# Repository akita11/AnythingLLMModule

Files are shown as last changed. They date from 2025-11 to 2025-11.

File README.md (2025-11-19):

# AnythingLLM Module

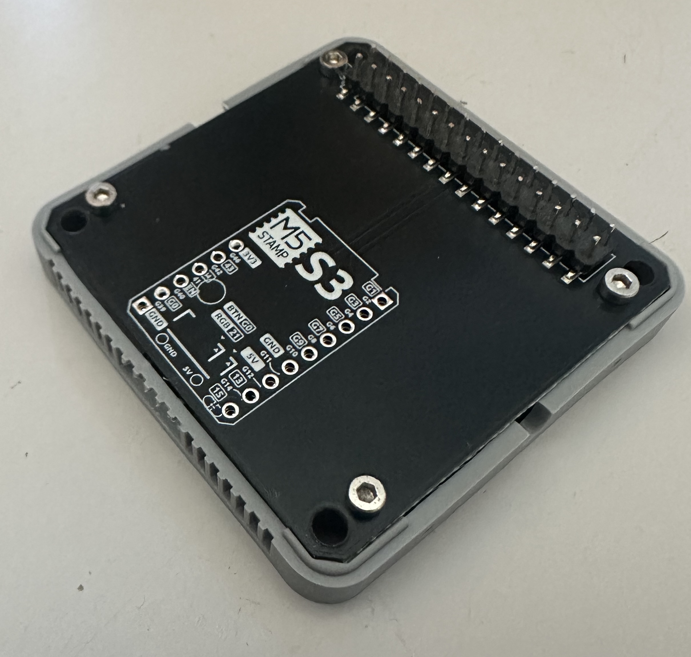
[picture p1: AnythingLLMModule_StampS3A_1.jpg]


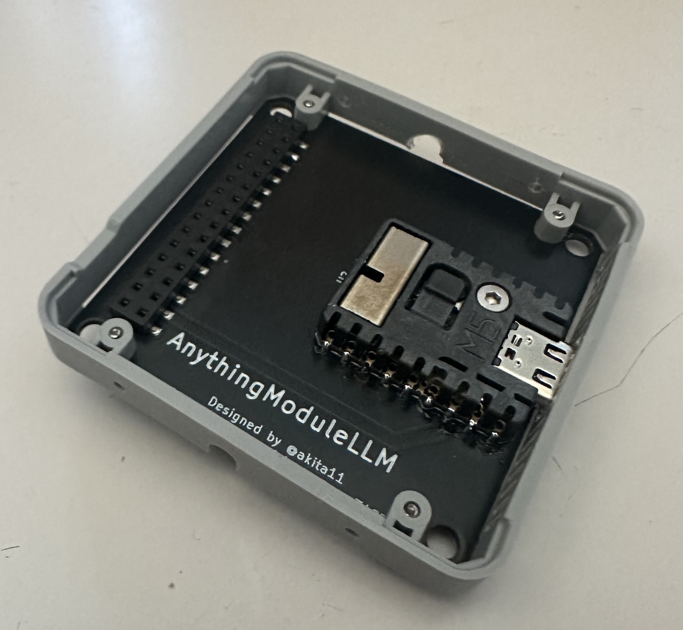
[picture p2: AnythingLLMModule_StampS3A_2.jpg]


M5Stack Coreシリーズに接続し、他のPC等で動作しているAIモデル（大規模言語モデル(LLM)）を、M5Stackから使用できるようにするModuleです。M5Stackとは、M5Stack社のLLM Moduleと同等の接続となるため、ソフトウエア的にはLLM Moduleと同様に扱うことができます。他のPCのLLMへはUSBやWiFiで接続します。M5StampS3Aに必要なソフトウエアを書き込んで使用してください。StampS3Aの取り付け方法が2種類あります。

## StampS3Aを直接とりつけ

[StampS3A](https://www.switch-science.com/products/10377)をリフローはんだ付け等で直接基板に実装します。M5Stack接続用のMbusコネクタもリフローはんだ付け等で基板に実装してください。また必要に応じて、Module Frameをとりつけてください。

## StampS3Aをコネクタを介してとりつけ

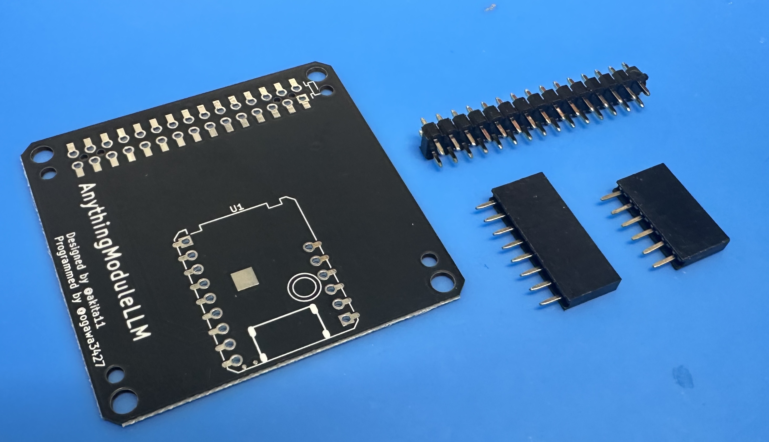
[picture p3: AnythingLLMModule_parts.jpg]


[2.54mmピンヘッダ実装済みのStampS3A](https://www.switch-science.com/products/10734)と、6pと9p（または8p）のピンソケット、およびMbusコネクタまたは2.54mmの2列x15ピンの低プロファイルのピンヘッダを用意します。

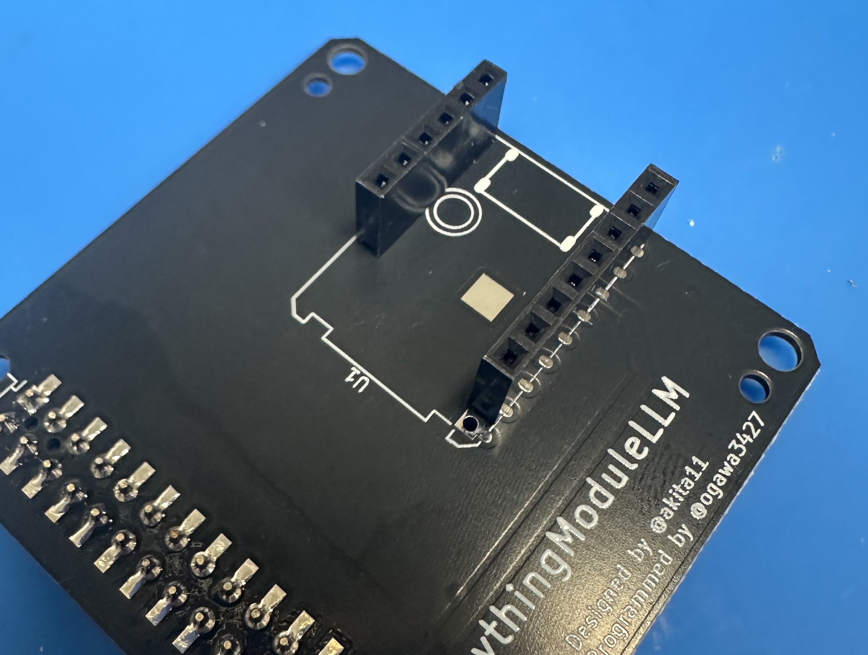
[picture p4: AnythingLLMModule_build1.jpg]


まず基板のこちら面に、6pと9p（または8p）のピンソケットをはんだ付けします。8pソケットを使う場合は、この写真のように1列分を開けた位置にとりつけてください。

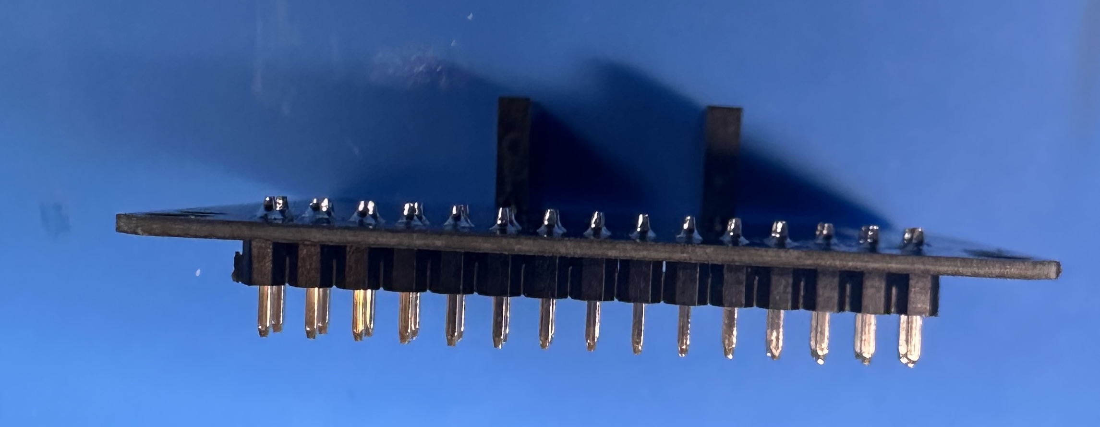
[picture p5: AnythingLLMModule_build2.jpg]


Mbusコネクタをはんだ付け、または2.54mmの2列x15ピンの低プロファイルのピンヘッダをこの写真のようにはんだ付けします。M5Stack本体に接続される側（この写真では下側）の端子の先端が、基板面から5.5mmの位置になるようにしてください。

最後に[2.54mmピンヘッダ実装済みのStampS3A](https://www.switch-science.com/products/10734)を取り付けて完成です。

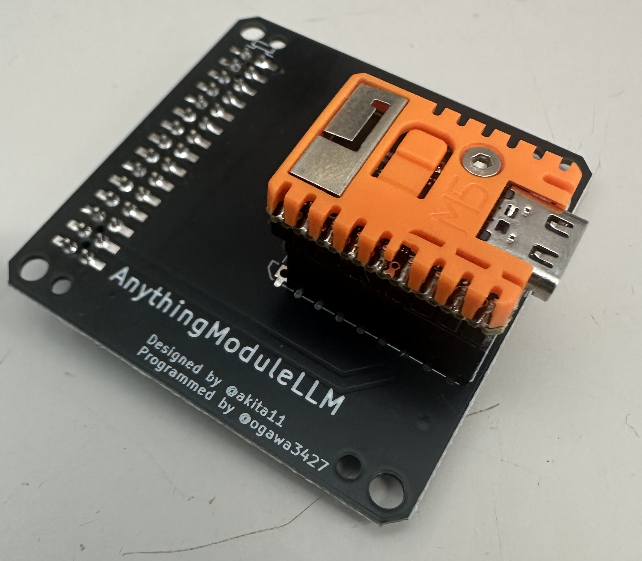
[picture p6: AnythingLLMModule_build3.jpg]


## ソフトウエア

Moduleに書き込む専用のファームウェアがあります。CoreからはLLM-Moduleのライブラリで通信できるように **「一部」** なっています。PC等との通信はWiFiまたはシリアル通信が選択できます。

### Module側

**USB-Cコネクタを接続する時に、ハンダ付けが取れないように注意してください！！！**  
**はがれやすい場合があるので、かならずStampS3を手で押さえて抜き差しすること！！！**  


PlatformIOで[stampS3R](https://github.com/akita11/AnythingLLMModule/tree/main/stampS3R)をビルドして、基板上のM5StampS3に書き込みます。  
このとき、`secrets.h`でPC等のローカルIPアドレス、WiFiのSSID/パスワードを設定してください。  

### PC側

現在はLLMサーバーとしてOllamaのみサポートしています。  
シリアルで接続する場合は[serial](https://github.com/akita11/AnythingLLMModule/tree/main/serial)にあるスクリプトを動かして待機させてください。  
WiFiで接続する場合はOllamaの設定から`Expose Ollama to the network`を有効にしてください。  

### サンプル

サンプルプログラム([coreS3_test](https://github.com/akita11/AnythingLLMModule/tree/main/coreS3_test))を用意しています。お使いのOllamaからアクセス可能なモデル名に変更してお試しください。画面に`ready`と表示されたら、シリアルモニタからテキストを入力してEnterキーを押すと、会話ができます。

### API対応状況(2025/11/20)

- [o] module_llm.checkConnection
- [o] module_llm.llm.setup
- [o] module_llm.llm.inferenceAndWaitResult

## Author

Designed by Junichi Akita (@akita11) / akita@ifdl.jp  
Programmed by Ogawa3427 / ogawa3427@ifdl.jp

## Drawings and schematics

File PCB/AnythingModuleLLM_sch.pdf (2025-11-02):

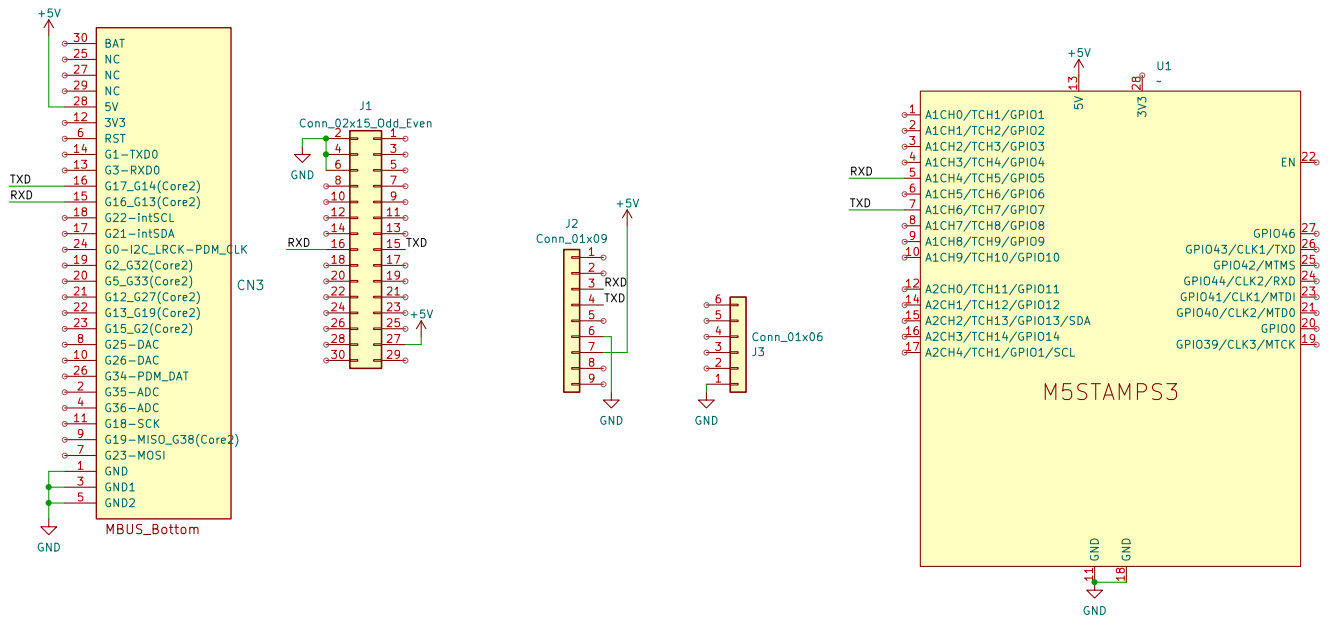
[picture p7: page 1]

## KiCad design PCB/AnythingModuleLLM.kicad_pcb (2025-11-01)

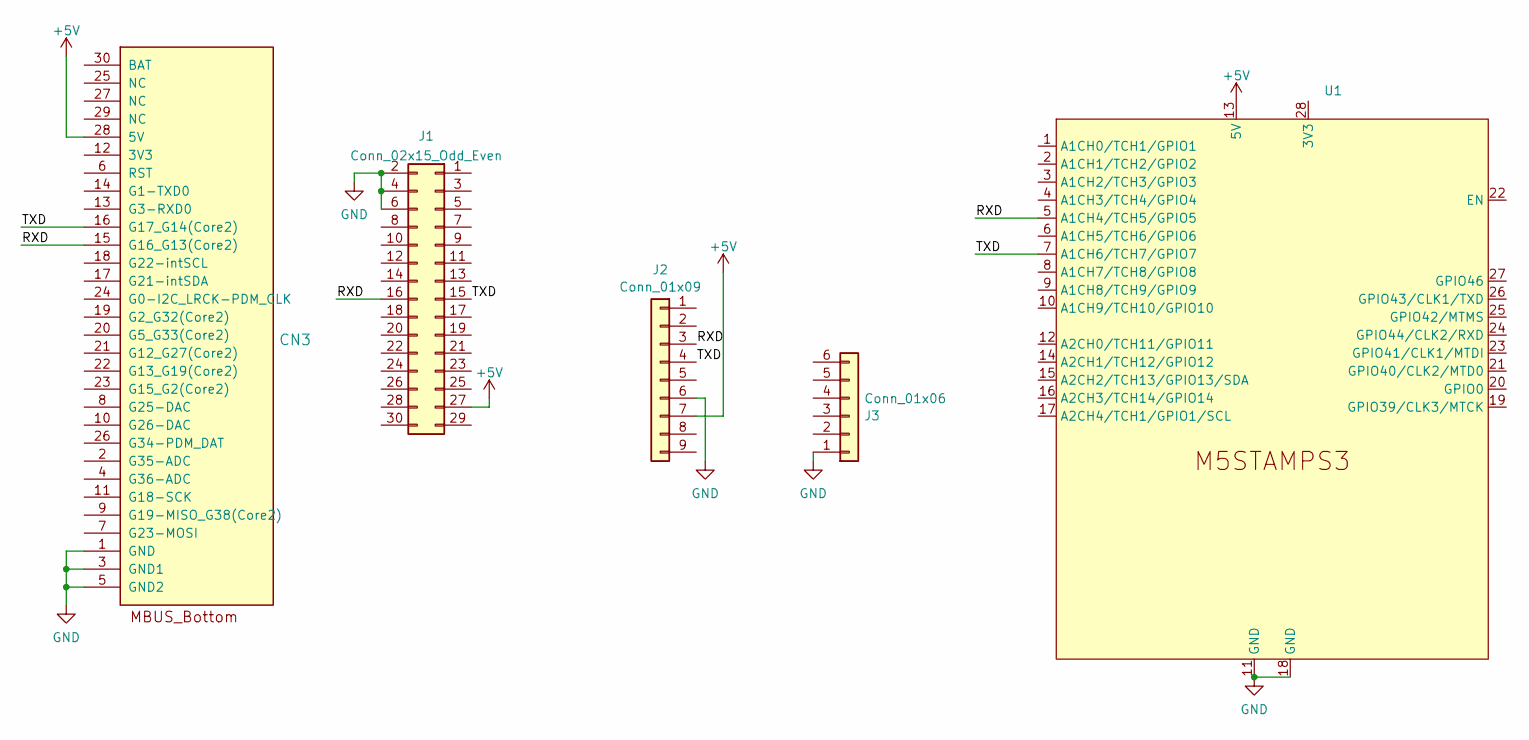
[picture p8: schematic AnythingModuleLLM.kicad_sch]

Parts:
CN3: CON_MBUS_bottom_Core2; M5STACK_BUS_30P
J1: Conn_02x15_Odd_Even; PinHeader_2x15_P2.54mm_Vertical
J2: Conn_01x09; PinHeader_1x09_P2.54mm_Vertical
J3: Conn_01x06; PinHeader_1x06_P2.54mm_Vertical
U1: STAMP-S3-SMD

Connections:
+5V: CN3.28 (5V), J1.27, J2.7, U1.13 (5V)
/RXD: CN3.15 (G16_G13(Core2)), J1.16, J2.3, U1.5 (A1CH4/TCH5/GPIO5)
/TXD: CN3.16 (G17_G14(Core2)), J1.15, J2.4, U1.7 (A1CH6/TCH7/GPIO7)
GND: CN3.1 (GND), CN3.3 (GND1), CN3.5 (GND2), J1.2, J1.4, J1.6, J2.6, J3.1, U1.11 (GND), U1.18 (GND)

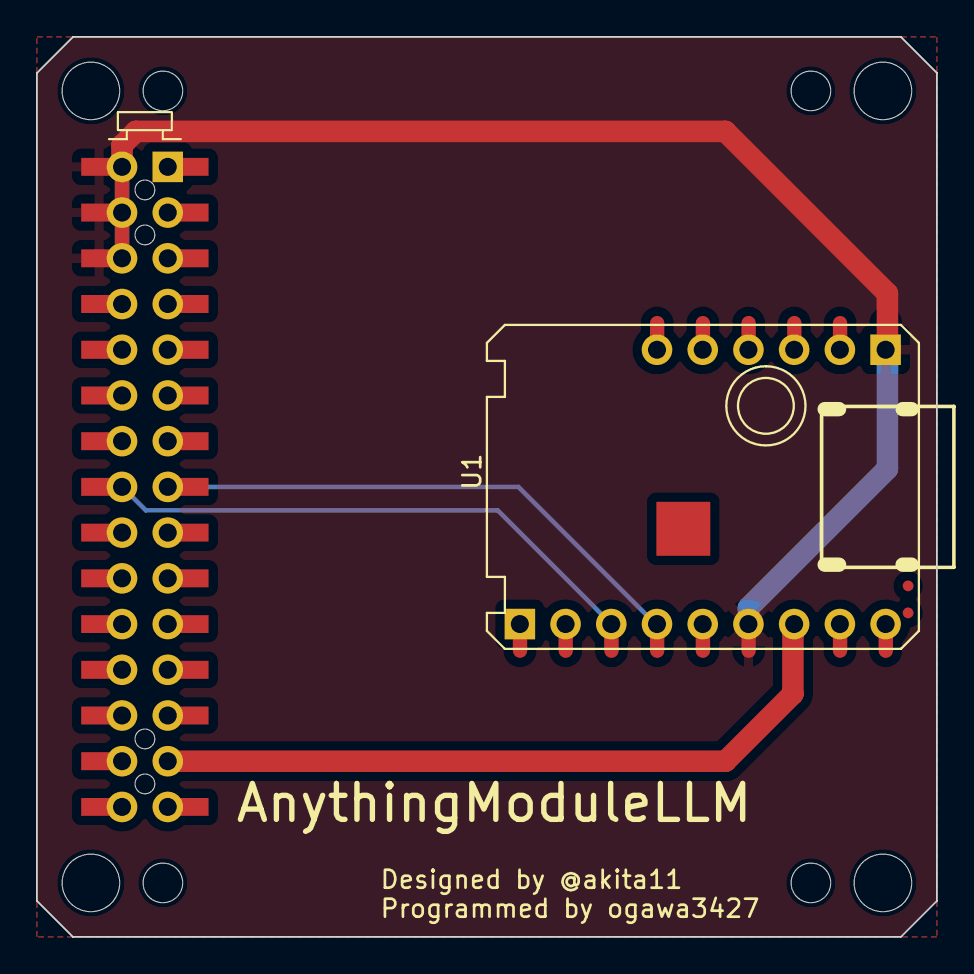
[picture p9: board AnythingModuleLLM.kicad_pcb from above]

Board: 2 copper layers, 50.0 x 50.0 mm, 5 parts (1 on the bottom side), 4 nets.

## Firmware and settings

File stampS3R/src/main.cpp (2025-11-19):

// true: WiFiでLLMサーバーと通信、false: シリアルでLLMサーバーと通信 (デフォルト: true)
#define USE_WIFI_FOR_LLM_COMMUNICATION true

// WiFiを使用するとき true: ステーションモード(既存のWiFiを使用)、false: APモード(これがAPになる) (デフォルト: true)
#define USE_STATION_MODE true

#include <M5Unified.h>
#include <ArduinoJson.h>
#include "common.h"

#if USE_WIFI_FOR_LLM_COMMUNICATION
#include "use_wifi.h"
#else
#include "use_serial.h"
#endif

void setup()
{
  auto cfg = M5.config();
  M5.begin(cfg);

  Serial.begin(9600);
  // Serial2.begin(115200, SERIAL_8N1, RX, TX) の順序
  Serial2.begin(115200, SERIAL_8N1, 7, 5);

  initLED();
  led_sayStart_initialize();
  // initSPIFFS();
  init_communication();
  led_saySuccess_initialize();

  Serial.println("[JSON] JSON reader initialized");
  resetJsonBuffer();
}

void loop()
{
  M5.update();

  // JSONドキュメントを動的に確保（必要に応じてサイズ調整）
  StaticJsonDocument<JSON_BUFFER_SIZE> doc;

  if (readJsonMessage(doc))
  {
    // JSONのパース成功
    Serial.println("[JSON] Parsed successfully:");

    Serial.println("[JSON] Sending handshake: Hello");
    Serial2.println("Hello");

    // JSONを整形して出力
    serializeJsonPretty(doc, Serial);
    Serial.println();

    // 返事用のJSONの元の構造体 をひとつ作る
    ResponseMsg_t response_msg = {};

    if (doc.containsKey("work_id") && doc.containsKey("action"))
    {
      if (doc["work_id"] == "sys")
      {
        response_msg.request_id = doc["request_id"].as<String>();
        response_msg.work_id = "sys";
        if (doc["action"] == "ping")
        {
          Serial.println("[JSON] System ping");
          response_msg.object = "None";
          response_msg.error.code = 0;
          response_msg.error.message = "";
          sendToM5(response_msg);
        }
        else if (doc["action"] == "reset")
        {
          Serial.println("[JSON] System reset");
          response_msg.object = "None";
          response_msg.error.code = 0;
          response_msg.error.message = "";
          response_msg.request_id = "sys_reset";
          response_msg.work_id = "sys";
          sendToM5(response_msg);
          delay(15);
          response_msg.request_id = "0";
          response_msg.work_id = "sys";
          response_msg.object = "None";
          response_msg.error.code = 0;
          response_msg.error.message = "";
          sendToM5(response_msg);
        }
        else if (doc["action"] == "reboot")
        {
          Serial.println("[JSON] System reboot");
        }
        else if (doc["action"] == "version")
        {
          Serial.println("[JSON] System version");
        }
      }
      else if (doc["work_id"] == "llm")
      {
        response_msg.request_id = doc["request_id"].as<String>();
        if (doc["action"] == "setup")
        {
          Serial.println("[JSON] LLM setup");
          // dataフィールドからモデル名を取得
          String model_name = "";
          if (doc["data"].is<JsonObject>())
          {
            JsonObject data_obj = doc["data"];
            if (data_obj["model"].is<String>())
            {
              model_name = data_obj["model"].as<String>();
            }
          }
          else if (doc["data"].is<String>())
          {
            model_name = doc["data"].as<String>();
          }

          if (model_name.length() == 0)
          {
            Serial.println("[JSON] Model name not specified in data field");
            response_msg.error.code = 1;
            response_msg.error.message = "Model name not specified";
            sendToM5(response_msg);
          }
          else
          {
            LLM_Status llm_status = llm_setup(model_name);
            Serial.print("[JSON] LLM setup status: ");
            Serial.println(llm_status);
            if (llm_status != LLM_OLLAMA_OK)
            {
              response_msg.error.code = (llm_status == LLM_OLLAMA_NOT_FOUND) ? 2 : 1;
              response_msg.error.message = (llm_status == LLM_OLLAMA_NOT_FOUND) ? "Model not found" : "LLM setup failed";
              sendToM5(response_msg);
            }
            else
            {
              // work_idを生成（例: "llm_12345"）
              String generated_work_id = "llm_" + String(millis() % 100000);
              response_msg.work_id = generated_work_id;
              current_work_id = generated_work_id;
              response_msg.object = "llm.setup";
              response_msg.error.code = 0;
              response_msg.error.message = "";
              response_msg.request_id = "llm_setup";
              Serial.print("[JSON] LLM setup response: ");
              Serial.print("request_id=");
              Serial.print(response_msg.request_id);
              Serial.print(", work_id=");
              Serial.print(response_msg.work_id);
              Serial.print(", object=");
              Serial.print(response_msg.object);
              Serial.print(", error.code=");
              Serial.print(response_msg.error.code);
              Serial.println();

              sendToM5(response_msg);

              // PCに送る（適当に受信したJSONをそのまま送る）
              String json_str;
              serializeJson(doc, json_str);
              sendToPC(json_str);
            }
          }
        }
        else if (doc["action"] == "inference")
        {
 
        }
      }
      else
      {
        if (doc["action"] == "inference" && doc["request_id"] == "llm_inference")
        {
          Serial.println("[JSON] LLM inference");
          if (doc["object"] == "llm.utf-8.stream")
          {
            Serial.println("[JSON] Using streaming inference");
            OllamaInferenceCommand command;
            command.model = using_model_name;
            command.prompt = doc["data"]["delta"].as<String>();

            LLM_Status llm_status = llm_inference_streaming(command);
            Serial.print("[JSON] LLM inference status: ");
            Serial.println(llm_status);
            if (llm_status != LLM_OLLAMA_OK)
            {
              response_msg.error.code = 1;
              response_msg.error.message = "LLM inference failed";
              sendToM5(response_msg);
            }
          }
          else
          {
            Serial.println("[JSON] Using non-streaming inference");
          }
        }
      }
    }
    // LEDで成功を表示
    blinkLED(COLOR_OK, 1, 50);
  }

  delay(10);
}

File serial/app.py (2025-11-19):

#!/usr/bin/env python3
# bidirectional_serial_http.py
# Python 3.8+
# Requires: aiohttp, pyserial-asyncio
# pip install aiohttp pyserial-asyncio

import asyncio
import argparse
import logging
from aiohttp import web, ClientSession
import serial_asyncio

logging.basicConfig(level=logging.INFO, format="%(asctime)s %(levelname)s: %(message)s")


async def serial_reader_task(reader, post_url, client_session, newline=b"\n"):
    """シリアルから行を読み、HTTP POSTで localhost の URL に送る"""
    while True:
        try:
            line = await reader.readuntil(newline)  # newlineで区切る
        except asyncio.IncompleteReadError as e:
            if e.partial:
                line = e.partial
            else:
                logging.info("serial: EOF")
                break
        except Exception as e:
            logging.exception("serial read error")
            await asyncio.sleep(1)
            continue

        # raw bytes のまま投げる（必要ならデコードして加工しても良い）
        logging.info("recv from serial: %r", line)
        try:
            async with client_session.post(post_url, data=line) as resp:
                logging.info("posted to %s -> %s", post_url, resp.status)
        except Exception:
            logging.exception("failed to post serial -> http")


async def handle_http_to_serial(request):
    """HTTP POST handler: body をそのままシリアルへ書く"""
    app = request.app
    writer = app["serial_writer"]
    if writer is None:
        return web.Response(status=503, text="serial not connected")

    data = await request.read()  # raw body
    if not data:
        return web.Response(status=400, text="empty body")

    try:
        # write and flush
        writer.write(data)
        # ensure newline (optionally)
        # writer.write(b"\n")
        await writer.drain()
        logging.info("wrote to serial: %r", data)
        return web.Response(status=200, text="ok")
    except Exception:
        logging.exception("failed to write to serial")
        return web.Response(status=500, text="failed to write to serial")


async def start_serial(app, port, baudrate, newline=b"\n"):
    """シリアル接続を開き、reader/writer を app に格納。reader タスク開始"""
    try:
        reader, writer = await serial_asyncio.open_serial_connection(url=port, baudrate=baudrate)
    except Exception:
        logging.exception("failed to open serial port %s", port)
        raise

    app["serial_writer"] = writer
    logging.info("serial opened %s @ %d", port, baudrate)

    # HTTPポスト先（シリアル->HTTP）
    post_url = app["post_url"]
    client_session = app["client_session"]
    app["serial_task"] = asyncio.create_task(serial_reader_task(reader, post_url, client_session, newline=newline))


async def stop_serial(app):
    task = app.get("serial_task")
    if task:
        task.cancel()
        try:
            await task
        except asyncio.CancelledError:
            pass

    writer = app.get("serial_writer")
    if writer:
        try:
            writer.close()
            await writer.wait_closed()
        except Exception:
            pass
    logging.info("serial stopped")


async def on_startup(app):
    await start_serial(app, app["serial_port"], app["baudrate"], newline=app["newline"])


async def on_cleanup(app):
    await stop_serial(app)
    cs = app.get("client_session")
    if cs:
        await cs.close()


def make_app(args):
    app = web.Application()
    app.add_routes([web.post('/to-serial', handle_http_to_serial)])
    # store config into app
    app["serial_port"] = args.port
    app["baudrate"] = args.baud
    app["post_url"] = args.post_url
    app["newline"] = args.newline.encode() if isinstance(args.newline, str) else args.newline
    app["serial_writer"] = None
    app["serial_task"] = None
    app["client_session"] = ClientSession()
    app.on_startup.append(on_startup)
    app.on_cleanup.append(on_cleanup)
    return app


def parse_args():
    p = argparse.ArgumentParser(description="Bidirectional bridge between serial and HTTP (localhost)")
    p.add_argument("--port", "-p", required=True, help="Serial device (e.g. /dev/ttyUSB0 or COM3)")
    p.add_argument("--baud", "-b", type=int, default=9600, help="Serial baudrate")
    p.add_argument("--http-host", default="127.0.0.1", help="Host for HTTP server (to receive -> serial)")
    p.add_argument("--http-port", type=int, default=8000, help="Port for HTTP server (to receive -> serial)")
    p.add_argument("--post-url", default="http://127.0.0.1:9000/from-serial", help="URL to POST serial->http messages")
    p.add_argument("--newline", default="\n", help="Line delimiter used for serial reading (default: LF)")
    return p.parse_args()


def main():
    args = parse_args()
    app = make_app(args)
    logging.info("HTTP server will listen on http://%s:%d", args.http_host, args.http_port)
    web.run_app(app, host=args.http_host, port=args.http_port)


if __name__ == "__main__":
    main()

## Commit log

2025-11-02 PCB folder
    [AnythingModuleLLM.kicad_pcb, AnythingModuleLLM.kicad_sch]
2025-11-06 wifi初期化関係
2025-11-06 長くなりそうなので複数ファイルに分割
2025-11-10 とりあえず何かの字が出る状態
2025-11-10 サンプルコードを追加
2025-11-12 json関係をmainから排除
2025-11-12 secretsの雛形
2025-11-12 python追加_動かない可能性が高い
2025-11-12 READMEに追記
